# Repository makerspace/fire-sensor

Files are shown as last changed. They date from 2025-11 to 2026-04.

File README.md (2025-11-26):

# Fire sensor for Stockholm Makerspace

This ESP32-based sensor monitors the fire-safety system of the [big dust collector](https://wiki.makerspace.se/Sp%C3%A5nsug,_Felder_RL_125) in the [Stockholm Makerspace](https://makerspace.se) Wood Workshop.
If a fire is detected, a POST request is sent to a URL, which will (presumably) then notify people that something bad is happening.

It monitors:

* A temperature sensor.
* A relay for the pressure sensor on the fire-safety system's water tank.
* A distance sensor, used for measuring the amount of dust in the dust bin.
* A relay for the distance sensor.

## Installation

### Pre-requisites

```bash
# Use Linux. It might be compatible with macOS, but likely not.

# Install rust
open https://rustup.rs/

cargo install ldproxy

# Install espup to manage the esp toolchain
cargo install espup --locked

# Install the esp toolchain
espup install

# Install espflash wrapper for cargo
cargo install cargo-espflash

# Clone this repository
git clone https://github.com/makerspace/fire-sensor.git
cd fire-sensor
```

### Flashing the ESP

The ESP supports both flashing via USB, and updates over wifi.

To flash via a connected USB cable, use
```bash
make flash
```

To flash to a powered-on ESP32 module on the same network, use:
```bash
make ota
```

Note: The MAC-address of the ESP32 module is hardcoded in the Makefile.

Note: The ESP32 will connect to the *Stockholm Makerspace Wifi* on startup. You must be on this network to be able to flash it wirelessly.

If the flash failed and the ESP32 cannot start properly, it will automatically revert to the previous firmware.

## Data logging

The ESP32 can connect to an MQTT broker (see config details in `main.rs`) to continuously log all sensor values.
This can also be used to send alerts, or even alerts for if the ESP32 loses power or breaks for some reason.

It will log the following data to the given MQTT topics:

```
sync/devices/{device_id}/status: JSON string, "online" | "offline". Uses MQTT last-will-and-testament to set the status to "offline" if the device goes down.
sync/devices/{device_id}/version: JSON string, "#{git hash} {timestamp}". The git hash of the commit the firmware was last flashed with, and the timestamp of the last build.
sync/dust_collector/{device_id}/temperature: Option<f32>, the temperature in degrees Celcius as given by the attached temperature sensor.
sync/dust_collector/{device_id}/water_pressure: Option<bool>, true when there's positive pressure.
sync/dust_collector/{device_id}/dust_level: Option<u16>, sensor value from the ultrasonic distance sensor.
sync/dust_collector/{device_id}/dust_level_warning_1: Option<bool>, true when the dust level is too high.
sync/dust_collector/{device_id}/dust_level_warning_2: Option<bool>, true when the dust level is very high and the machine will be turned off.
sync/dust_collector/{device_id}/machine_running: Option<bool>, true when the machine is running.
sync/dust_collector/{device_id}/powered_on_too_long: Option<bool>, true when the gates have been opened for too long, and the machine has been turned off automatically.
sync/dust_collector/{device_id}/gates/N/open: Option<bool>, true when the gate is open
```

Where `device_id` is `fire_sensor {MAC ADDRESS OF ESP32}`.

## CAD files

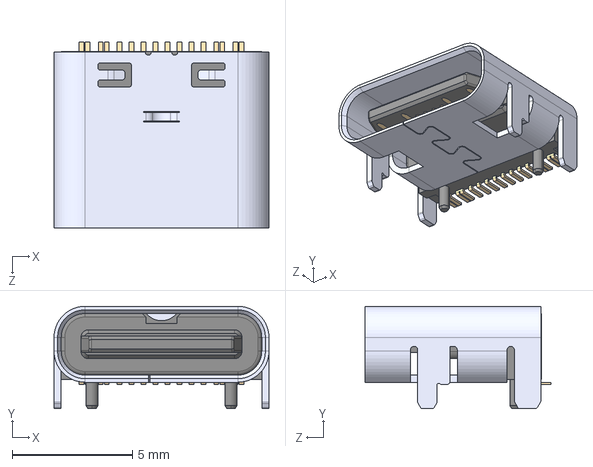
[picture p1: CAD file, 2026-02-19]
schematic2/3D_models/CSP-USC16-TR--3DModel-STEP-468060.STEP
8.94 x 4.26 x 7.75 mm

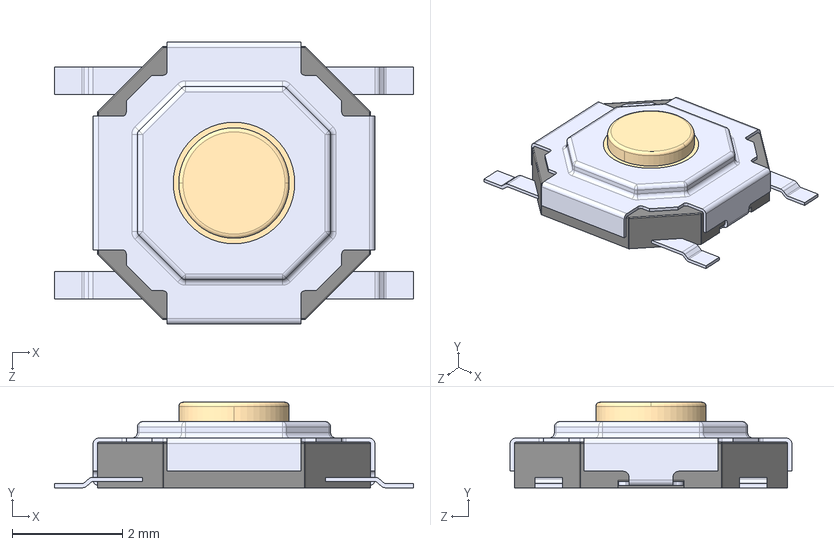
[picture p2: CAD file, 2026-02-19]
schematic2/3D_models/TS-1187A-B-A-B--3DModel-STEP-56544.STEP
6.50 x 1.55 x 5.10 mm

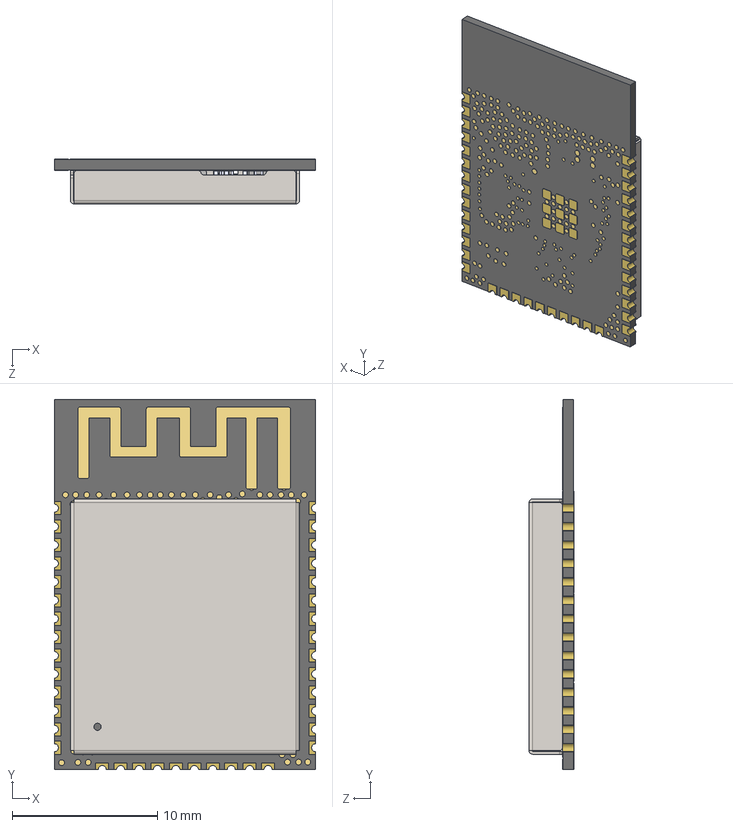
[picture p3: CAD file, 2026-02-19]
schematic2/3D_models/ESP32-WROOM-32E.STEP
18.0 x 25.5 x 3.10 mm
ESP32_5x5_20210301.STEP^ESP32_5x5_20210301.STEP_Submodel-SLP48_5X5_part_DesignRootModel_PCB_ESP32-WROOM-32E_V1(2)_PCB_ESP32-WROOM-32E_V1
trace_1^Submodel-ANT_L_TYPEA_1501846164_part_DesignRootModel_PCB_ESP32-WROOM-32E_V1(2)_PCB_ESP32-WROOM-32E_V1
DFN1006.STEP^DFN1006.STEP_Submodel-SOD882_part_DesignRootModel_PCB_ESP32-WROOM-32E_V1(2)_PCB_ESP32-WROOM-32E_V1
R0201_20210301.STEP^R0201_20210301.STEP_Submodel-R0201_part_DesignRootModel_PCB_ESP32-WROOM-32E_V1(2)_PCB_ESP32-WROOM-32E_V1 x 3
L0201_20210301.STEP^L0201_20210301.STEP_Submodel-L0201_part_DesignRootModel_PCB_ESP32-WROOM-32E_V1(2)_PCB_ESP32-WROOM-32E_V1 x 2
C0201_20210301.STEP^C0201_20210301.STEP_Submodel-C0201_part_DesignRootModel_PCB_ESP32-WROOM-32E_V1(2)_PCB_ESP32-WROOM-32E_V1 x 17
SOIC8_208_20210301.STEP^SOIC8_208_20210301.STEP_Submodel-SOIC08-WN_part_DesignRootModel_PCB_ESP32-WROOM-32E_V1(2)_PCB_ESP32-WROOM-32E_V1
XTAL3225_20210301.STEP^XTAL3225_20210301.STEP_Submodel-3225_part_DesignRootModel_PCB_ESP32-WROOM-32E_V1(2)_PCB_ESP32-WROOM-32E_V1
C0402_20210301.STEP^C0402_20210301.STEP_Submodel-0402A_part_DesignRootModel_PCB_ESP32-WROOM-32E_V1(2)_PCB_ESP32-WROOM-32E_V1 x 2
uid__1-311^DesignRootModel_PCB_ESP32-WROOM-32E_V1(2)_PCB_ESP32-WROOM-32E_V1
uid__1-312^DesignRootModel_PCB_ESP32-WROOM-32E_V1(2)_PCB_ESP32-WROOM-32E_V1
uid__1-313^DesignRootModel_PCB_ESP32-WROOM-32E_V1(2)_PCB_ESP32-WROOM-32E_V1
uid__1-314^DesignRootModel_PCB_ESP32-WROOM-32E_V1(2)_PCB_ESP32-WROOM-32E_V1
uid__1-315^DesignRootModel_PCB_ESP32-WROOM-32E_V1(2)_PCB_ESP32-WROOM-32E_V1
uid__1-316^DesignRootModel_PCB_ESP32-WROOM-32E_V1(2)_PCB_ESP32-WROOM-32E_V1
uid__1-317^DesignRootModel_PCB_ESP32-WROOM-32E_V1(2)_PCB_ESP32-WROOM-32E_V1
uid__1-318^DesignRootModel_PCB_ESP32-WROOM-32E_V1(2)_PCB_ESP32-WROOM-32E_V1
uid__1-319^DesignRootModel_PCB_ESP32-WROOM-32E_V1(2)_PCB_ESP32-WROOM-32E_V1
uid__1-320^DesignRootModel_PCB_ESP32-WROOM-32E_V1(2)_PCB_ESP32-WROOM-32E_V1
uid__1-321^DesignRootModel_PCB_ESP32-WROOM-32E_V1(2)_PCB_ESP32-WROOM-32E_V1
uid__1-322^DesignRootModel_PCB_ESP32-WROOM-32E_V1(2)_PCB_ESP32-WROOM-32E_V1
uid__1-323^DesignRootModel_PCB_ESP32-WROOM-32E_V1(2)_PCB_ESP32-WROOM-32E_V1
uid__1-324^DesignRootModel_PCB_ESP32-WROOM-32E_V1(2)_PCB_ESP32-WROOM-32E_V1
uid__1-325^DesignRootModel_PCB_ESP32-WROOM-32E_V1(2)_PCB_ESP32-WROOM-32E_V1
uid__1-326^DesignRootModel_PCB_ESP32-WROOM-32E_V1(2)_PCB_ESP32-WROOM-32E_V1
uid__1-327^DesignRootModel_PCB_ESP32-WROOM-32E_V1(2)_PCB_ESP32-WROOM-32E_V1
uid__1-328^DesignRootModel_PCB_ESP32-WROOM-32E_V1(2)_PCB_ESP32-WROOM-32E_V1
uid__1-329^DesignRootModel_PCB_ESP32-WROOM-32E_V1(2)_PCB_ESP32-WROOM-32E_V1
uid__1-330^DesignRootModel_PCB_ESP32-WROOM-32E_V1(2)_PCB_ESP32-WROOM-32E_V1
uid__1-331^DesignRootModel_PCB_ESP32-WROOM-32E_V1(2)_PCB_ESP32-WROOM-32E_V1
uid__1-332^DesignRootModel_PCB_ESP32-WROOM-32E_V1(2)_PCB_ESP32-WROOM-32E_V1
uid__1-333^DesignRootModel_PCB_ESP32-WROOM-32E_V1(2)_PCB_ESP32-WROOM-32E_V1
uid__1-334^DesignRootModel_PCB_ESP32-WROOM-32E_V1(2)_PCB_ESP32-WROOM-32E_V1
uid__1-335^DesignRootModel_PCB_ESP32-WROOM-32E_V1(2)_PCB_ESP32-WROOM-32E_V1
uid__1-336^DesignRootModel_PCB_ESP32-WROOM-32E_V1(2)_PCB_ESP32-WROOM-32E_V1
uid__1-337^DesignRootModel_PCB_ESP32-WROOM-32E_V1(2)_PCB_ESP32-WROOM-32E_V1
uid__1-338^DesignRootModel_PCB_ESP32-WROOM-32E_V1(2)_PCB_ESP32-WROOM-32E_V1
uid__1-339^DesignRootModel_PCB_ESP32-WROOM-32E_V1(2)_PCB_ESP32-WROOM-32E_V1
uid__1-340^DesignRootModel_PCB_ESP32-WROOM-32E_V1(2)_PCB_ESP32-WROOM-32E_V1
uid__1-341^DesignRootModel_PCB_ESP32-WROOM-32E_V1(2)_PCB_ESP32-WROOM-32E_V1
uid__1-342^DesignRootModel_PCB_ESP32-WROOM-32E_V1(2)_PCB_ESP32-WROOM-32E_V1
uid__1-343^DesignRootModel_PCB_ESP32-WROOM-32E_V1(2)_PCB_ESP32-WROOM-32E_V1
uid__1-344^DesignRootModel_PCB_ESP32-WROOM-32E_V1(2)_PCB_ESP32-WROOM-32E_V1
uid__1-345^DesignRootModel_PCB_ESP32-WROOM-32E_V1(2)_PCB_ESP32-WROOM-32E_V1
uid__1-346^DesignRootModel_PCB_ESP32-WROOM-32E_V1(2)_PCB_ESP32-WROOM-32E_V1
uid__1-347^DesignRootModel_PCB_ESP32-WROOM-32E_V1(2)_PCB_ESP32-WROOM-32E_V1
uid__1-348^DesignRootModel_PCB_ESP32-WROOM-32E_V1(2)_PCB_ESP32-WROOM-32E_V1
uid__1-349^DesignRootModel_PCB_ESP32-WROOM-32E_V1(2)_PCB_ESP32-WROOM-32E_V1
uid__1-350^DesignRootModel_PCB_ESP32-WROOM-32E_V1(2)_PCB_ESP32-WROOM-32E_V1
uid__1-351^DesignRootModel_PCB_ESP32-WROOM-32E_V1(2)_PCB_ESP32-WROOM-32E_V1
uid__1-352^DesignRootModel_PCB_ESP32-WROOM-32E_V1(2)_PCB_ESP32-WROOM-32E_V1
uid__1-353^DesignRootModel_PCB_ESP32-WROOM-32E_V1(2)_PCB_ESP32-WROOM-32E_V1
uid__1-354^DesignRootModel_PCB_ESP32-WROOM-32E_V1(2)_PCB_ESP32-WROOM-32E_V1
uid__1-355^DesignRootModel_PCB_ESP32-WROOM-32E_V1(2)_PCB_ESP32-WROOM-32E_V1
uid__1-356^DesignRootModel_PCB_ESP32-WROOM-32E_V1(2)_PCB_ESP32-WROOM-32E_V1
uid__1-357^DesignRootModel_PCB_ESP32-WROOM-32E_V1(2)_PCB_ESP32-WROOM-32E_V1
uid__1-359^DesignRootModel_PCB_ESP32-WROOM-32E_V1(2)_PCB_ESP32-WROOM-32E_V1
uid__1-360^DesignRootModel_PCB_ESP32-WROOM-32E_V1(2)_PCB_ESP32-WROOM-32E_V1
uid__1-361^DesignRootModel_PCB_ESP32-WROOM-32E_V1(2)_PCB_ESP32-WROOM-32E_V1
uid__1-362^DesignRootModel_PCB_ESP32-WROOM-32E_V1(2)_PCB_ESP32-WROOM-32E_V1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

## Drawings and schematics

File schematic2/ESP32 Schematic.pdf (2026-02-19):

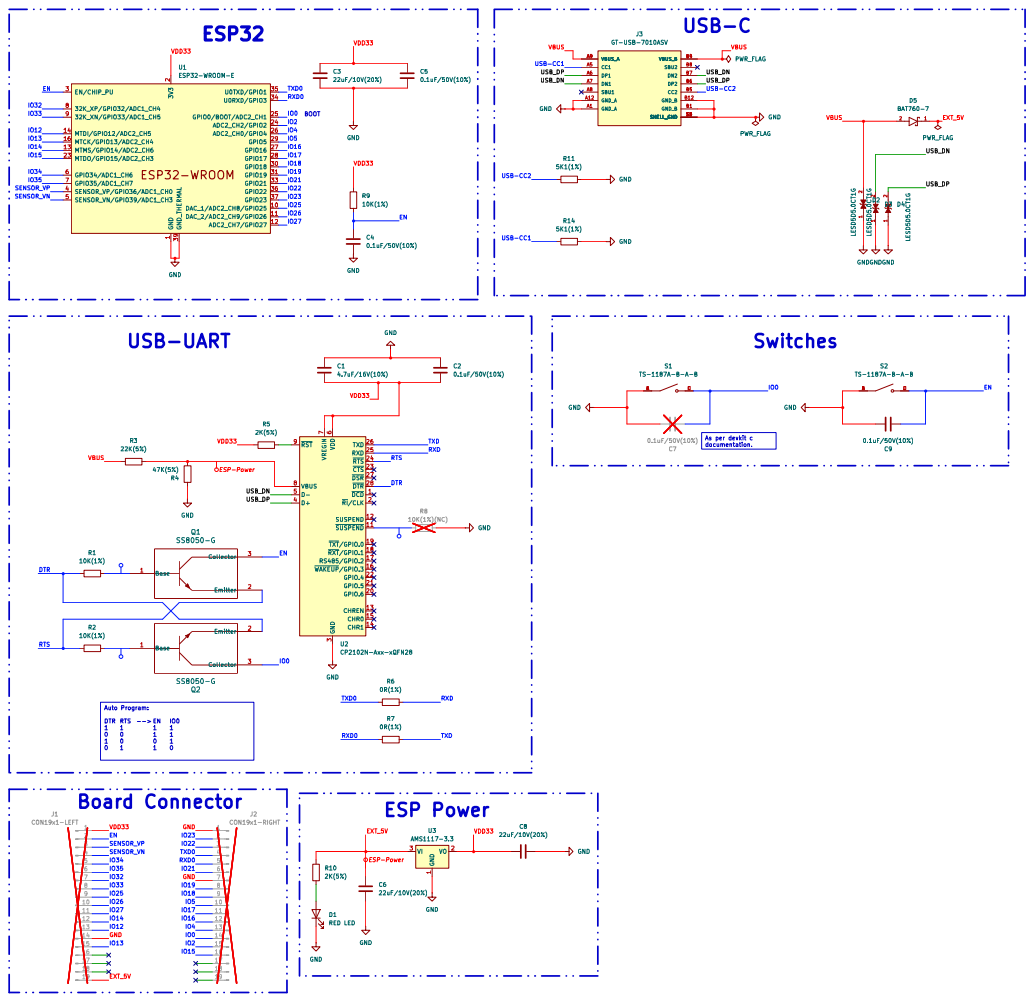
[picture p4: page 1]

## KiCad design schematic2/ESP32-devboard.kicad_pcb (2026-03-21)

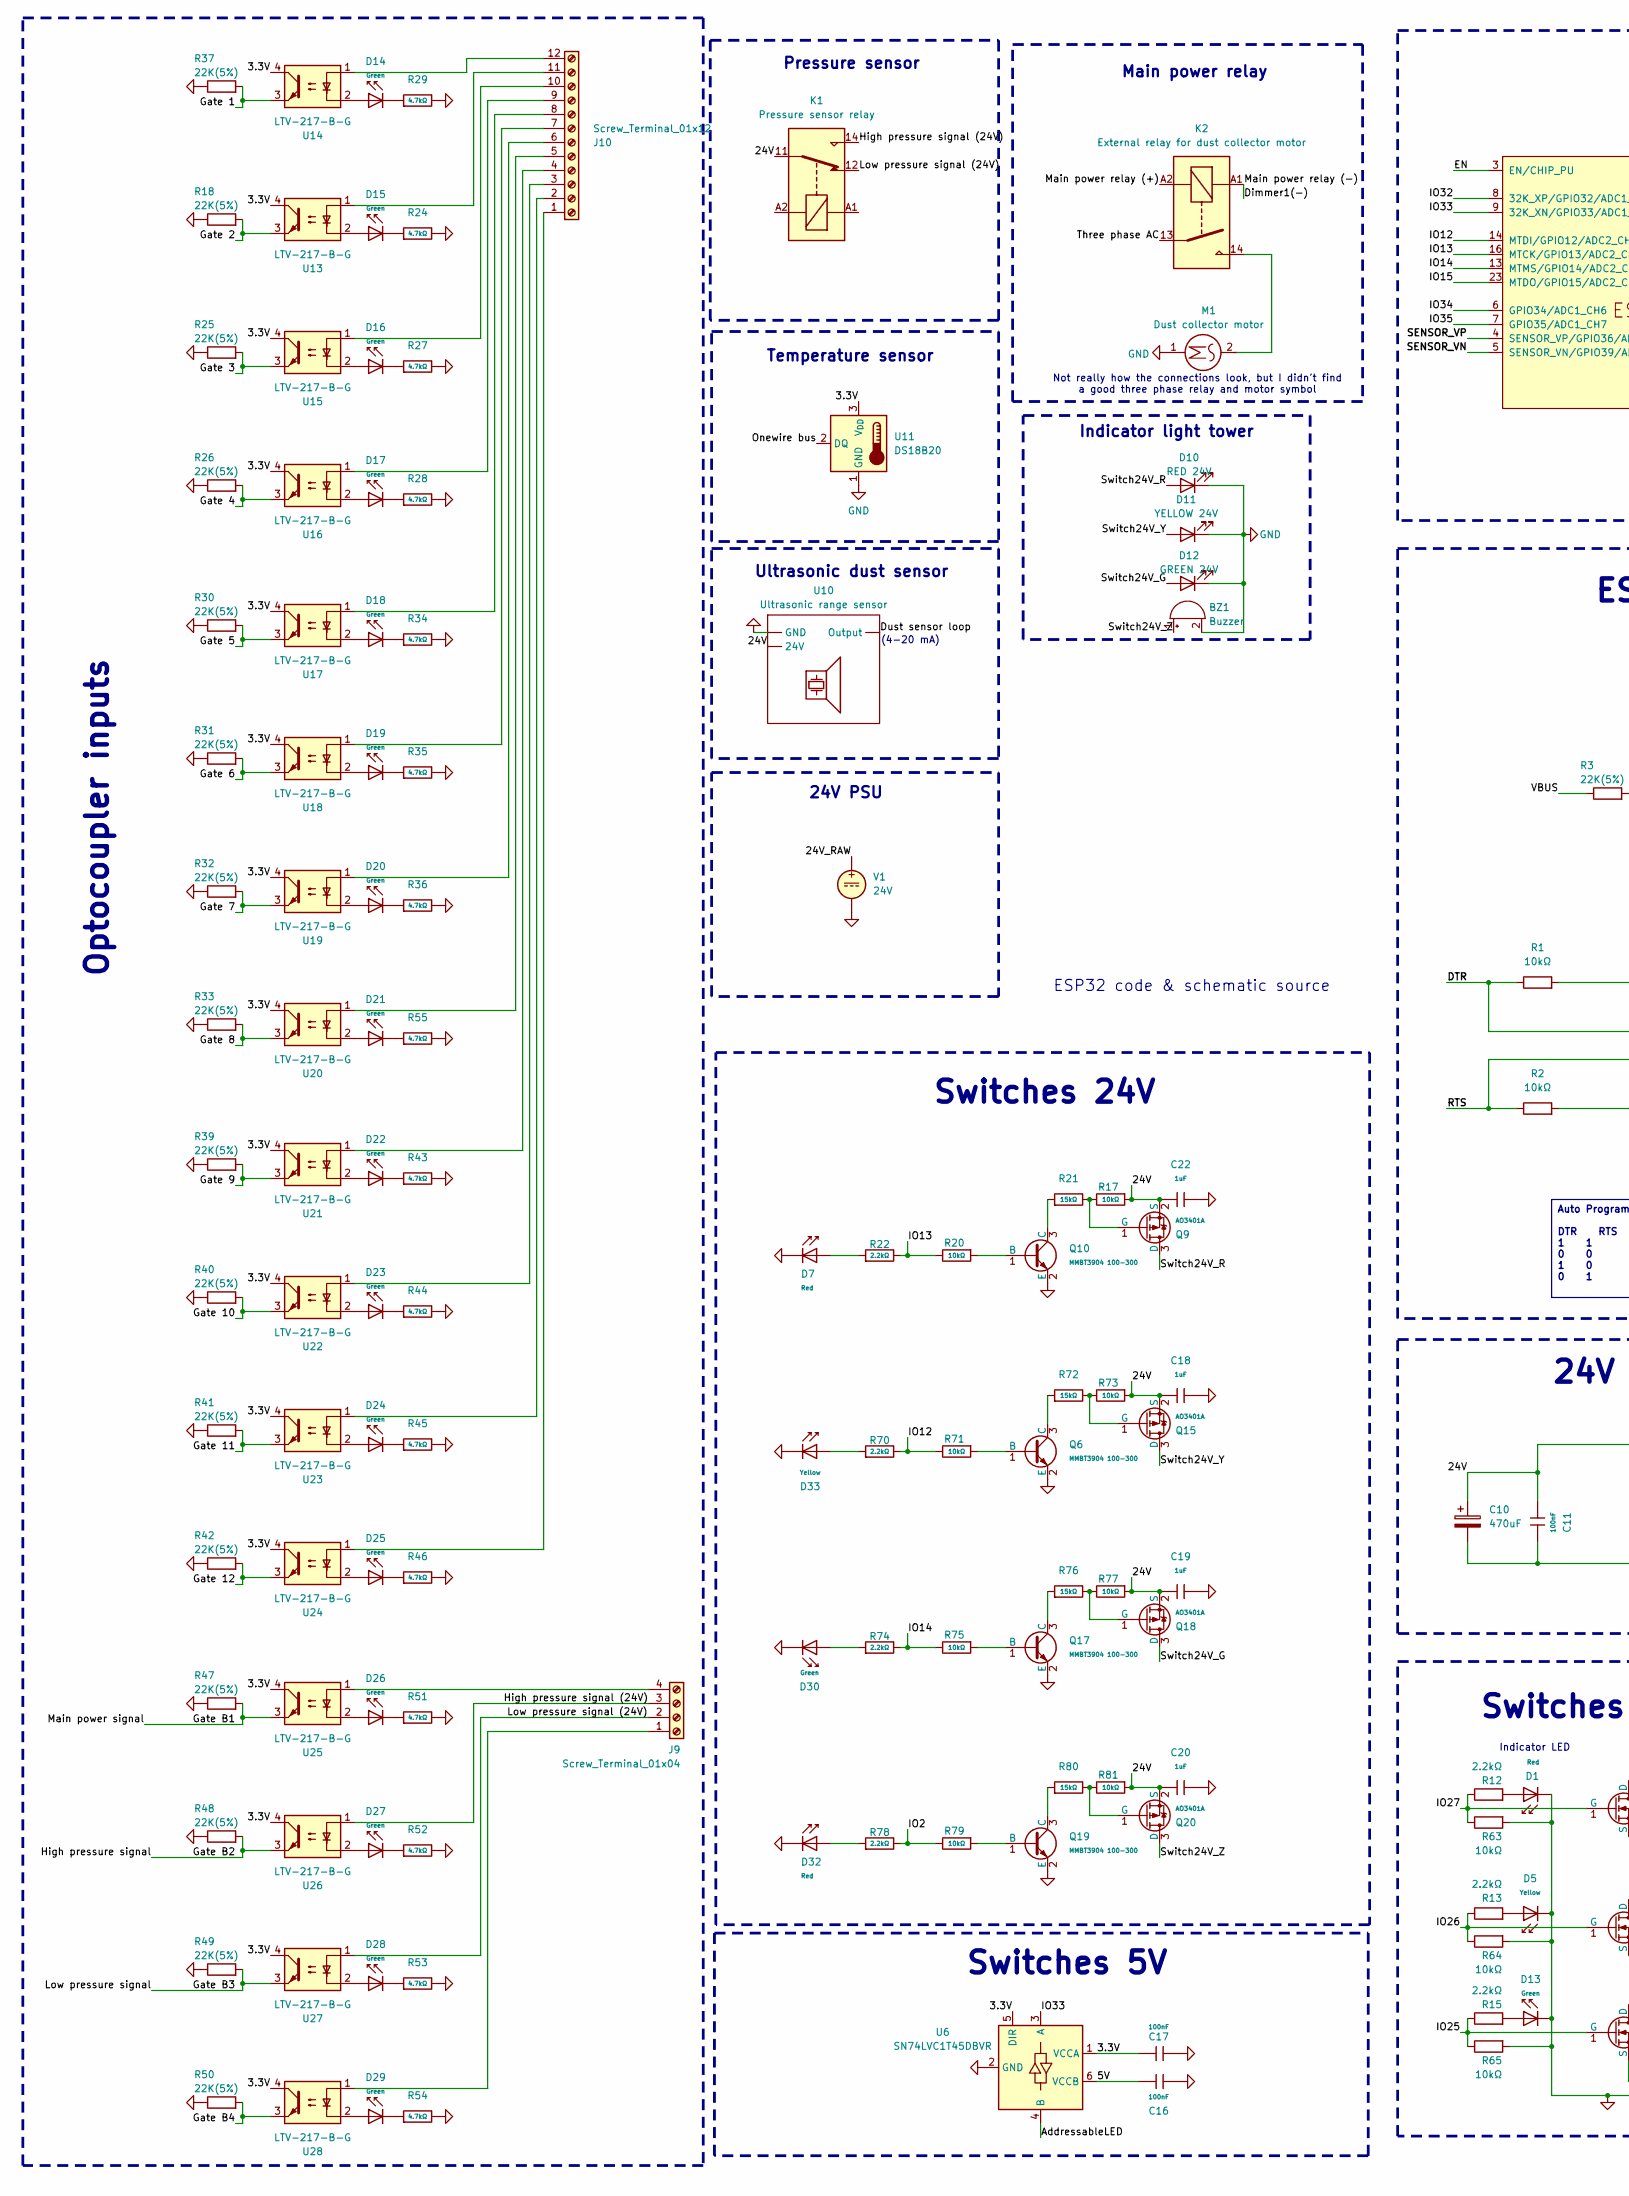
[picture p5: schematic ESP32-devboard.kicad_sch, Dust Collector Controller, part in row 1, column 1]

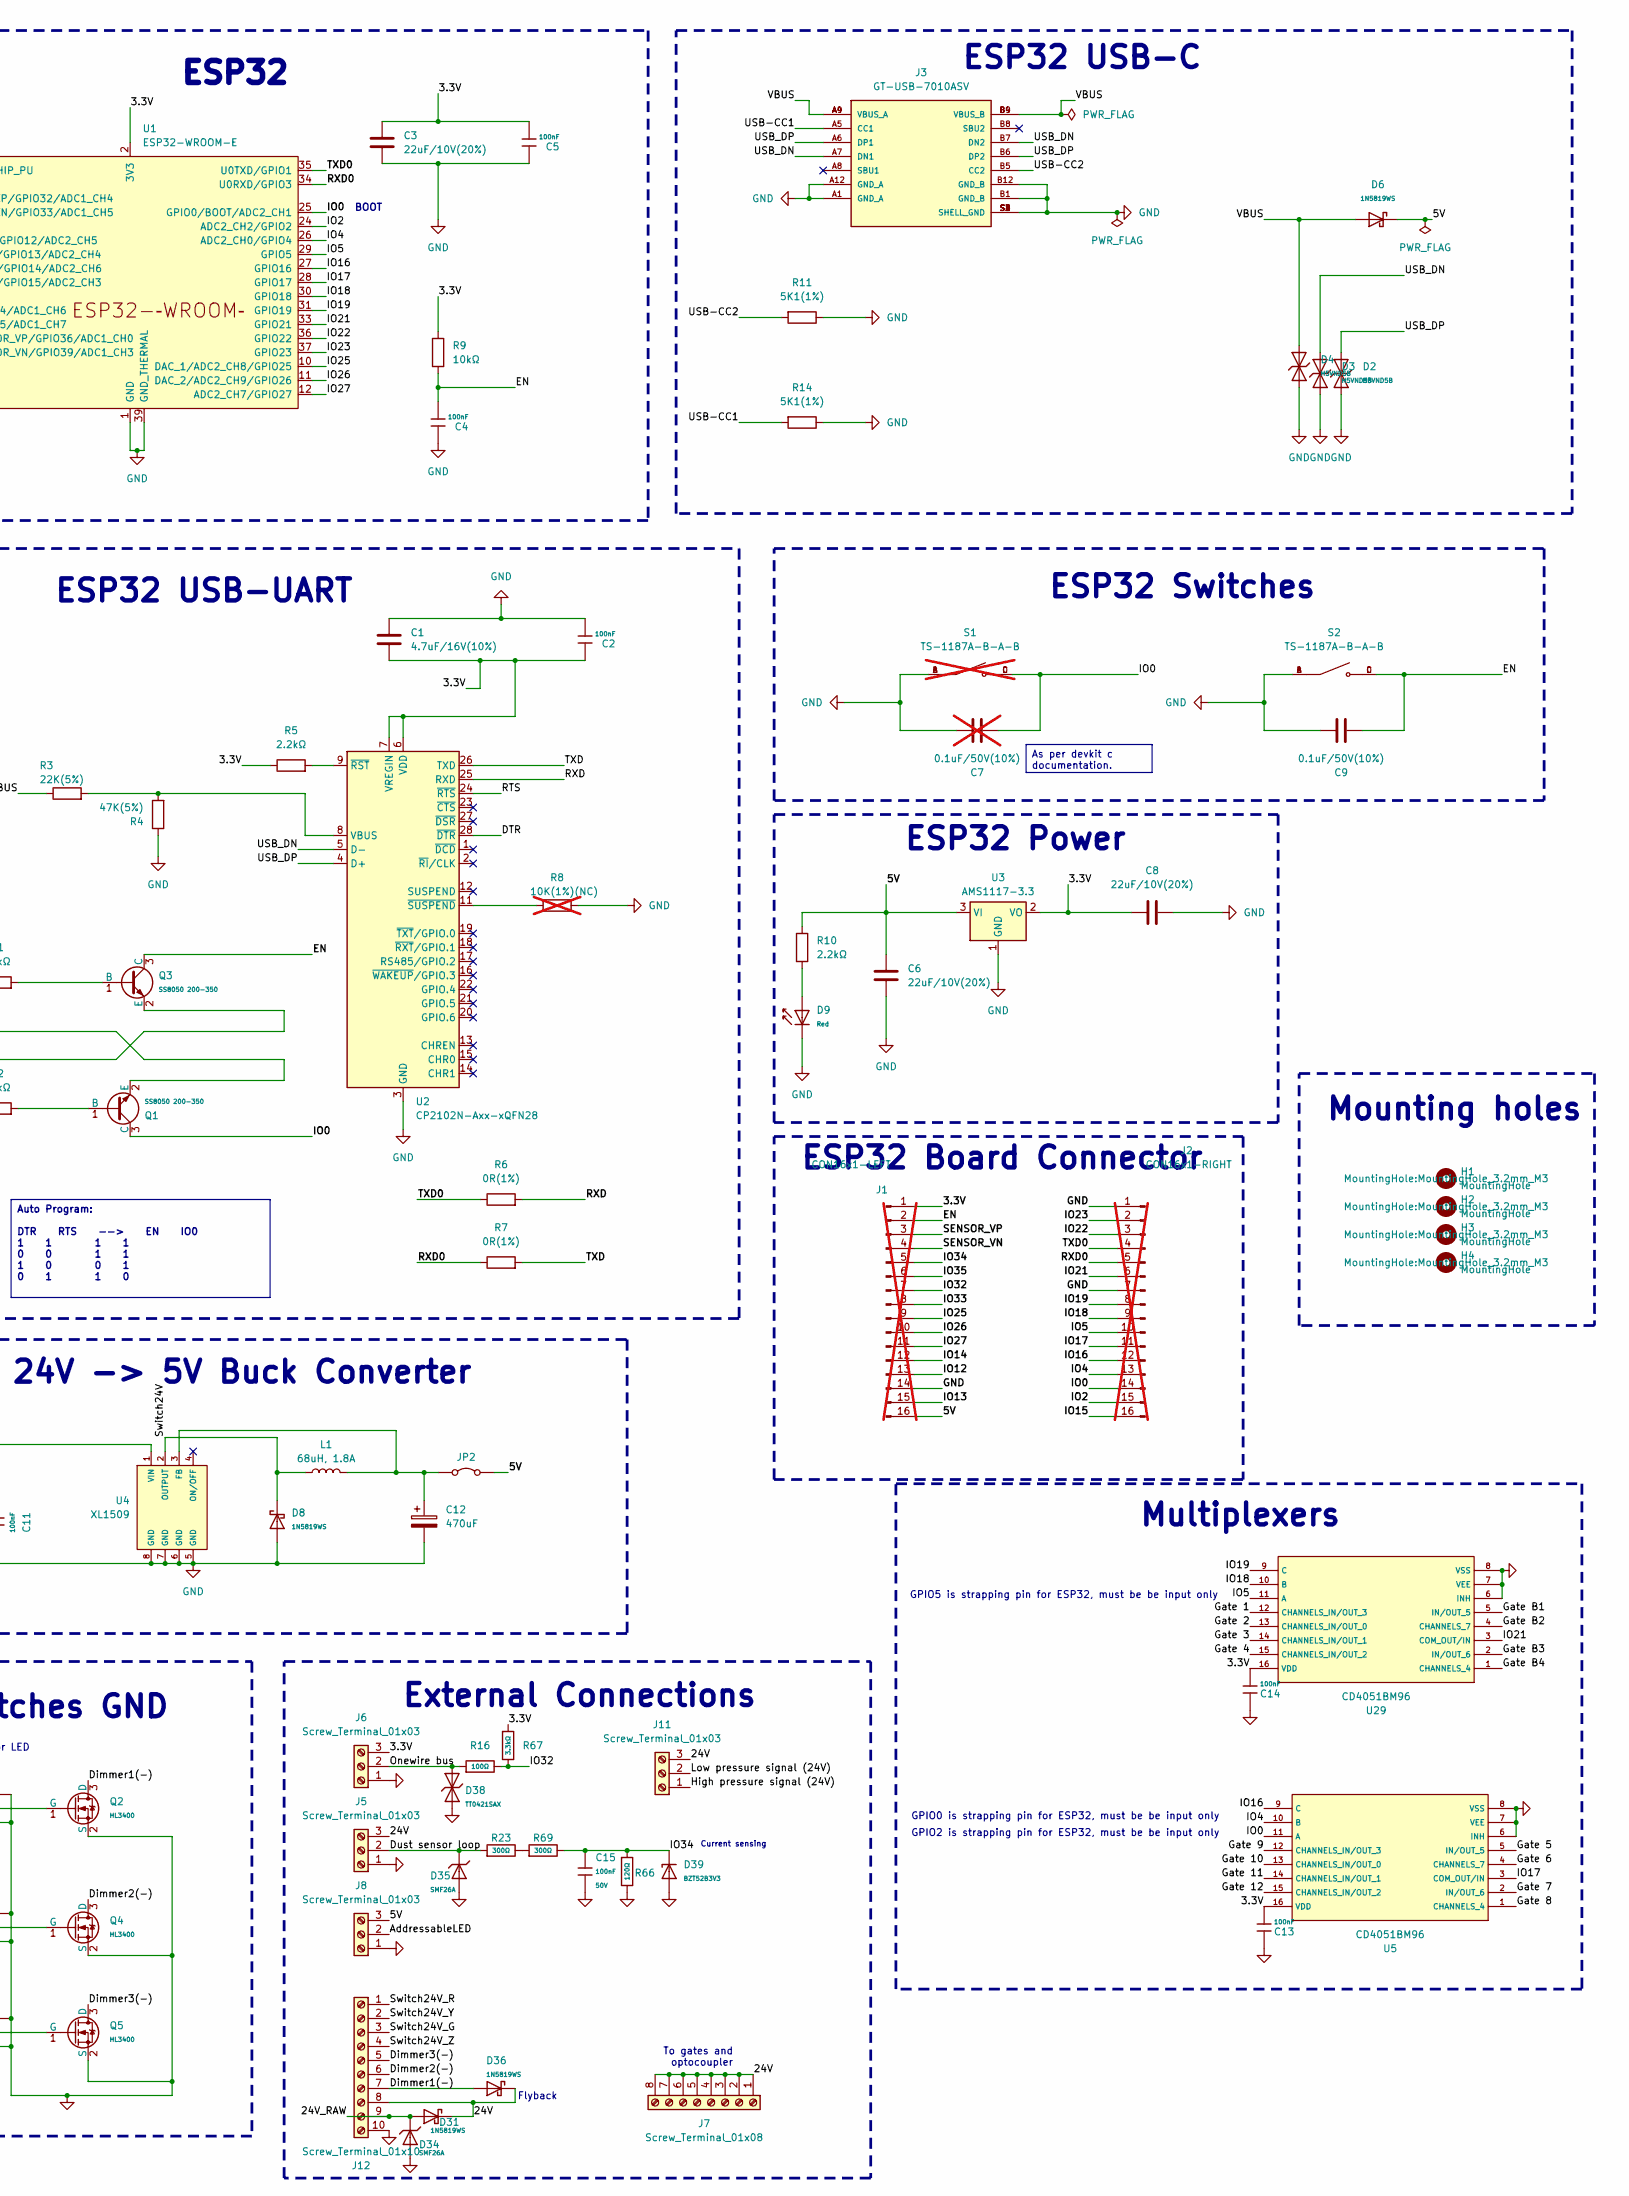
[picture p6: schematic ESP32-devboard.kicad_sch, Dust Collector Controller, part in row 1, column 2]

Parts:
BZ1: Buzzer
C1: 4.7uF/16V(10%); C_0603_1608Metric; LCSC C19666
C2, C4, C5, C11, C13, C14, C15, C16, C17: 100nF; C_0603; Voltage Rated 50V; Tolerance ±10%; Part CC0603KRX7R9BB104; LCSC C14663
C3, C6, C8: 22uF/10V(20%); C_0805_2012Metric; LCSC C45783
C7: 0.1uF/50V(10%); C_0402_1005Metric; LCSC C307331; not fitted
C9: 0.1uF/50V(10%); C_0402_1005Metric; LCSC C307331
C10, C12: 470uF; CP_Radial_D10.0mm_P5.00mm
C18, C19, C20, C22: 1uF; C_0603; Voltage Rated 50V; Tolerance ±10%; Part CL10A105KB8NNNC; LCSC C15849
D1, D7, D9, D32: Red; D_0603; Part KT-0603R; LCSC C2286
D2, D3, D4: H5VND5B; D_SOD-523; Part H5VND5B; LCSC C20615818
D5, D33: Yellow; D_0805; Part KT-0805Y; LCSC C2296
D6, D8, D31, D36: 1N5819WS; D_SOD-323; Forward Voltage (Vf@If) 600mV@1A; Reverse Voltage (Vr) 40V; Part 1N5819WS; LCSC C191023
D10: RED 24V
D11: YELLOW 24V
D12: GREEN 24V
D13, D14, D15, D16, D17, D18, D19, D20, D21, D22, D23, D24, D25, D26, D27, D28, D29, D30: Green; D_0805; Part KT-0805G; LCSC C2297
D34, D35: SMF26A; D_SOD-123FL; Clamping Voltage 42.1V; Voltage - Breakdown 31.9V; Part SMF26A; LCSC C41376090
D38: TT0421SAX; D_DFN0603-2L; Clamping Voltage 4.5V; Voltage Breakdown 9V; Part TT0421SAX; LCSC C5364033
D39: BZT52B3V3; D_SOD-123; Part BZT52B3V3; LCSC C19077392
H1, H2, H3, H4: MountingHole; MountingHole_3.2mm_M3
J1: CON16x1-LEFT; PinSocket_1x16_P2.54mm_Vertical; not fitted
J2: CON16x1-RIGHT; PinSocket_1x16_P2.54mm_Vertical; not fitted
J3: GT-USB-7010ASV; GT-USB-7010; LCSC C2988369
J5, J6, J8, J11: Screw_Terminal_01x03; PinHeader_1x03_P2.54mm_Horizontal
J7: Screw_Terminal_01x08; TerminalBlock_Phoenix_MKDS-1,5-8_1x08_P5.00mm_Horizontal
J9: Screw_Terminal_01x04; TerminalBlock_Phoenix_MKDS-1,5-4_1x04_P5.00mm_Horizontal
J10: Screw_Terminal_01x12; TerminalBlock_Phoenix_MKDS-1,5-12_1x12_P5.00mm_Horizontal
J12: Screw_Terminal_01x10; TerminalBlock_Phoenix_MKDS-1,5-10_1x10_P5.00mm_Horizontal
JP2: Jumper_2_Bridged; PinHeader_1x02_P2.54mm_Vertical
K1: Pressure sensor relay; Relay_SPDT_Fujitsu_FTR-LYCA005x_FormC_Vertical
K2: External relay for dust collector motor; Relay_SPST-NO_Fujitsu_FTR-LYAA005x_FormA_Vertical
L1: 68uH, 1.8A; Inductor C5189964; LCSC C5189964
M1: Dust collector motor
Q1, Q3: SS8050 200-350; Q_SOT-23; Part SS8050(RANGE:200-350); LCSC C2150
Q2, Q4, Q5: HL3400; Q_SOT-23; Part HL3400; LCSC C22469448
Q6, Q10, Q17, Q19: MMBT3904 100-300; Q_SOT-23; Part MMBT3904(RANGE:100-300); LCSC C20526
Q9, Q15, Q18, Q20: AO3401A; Q_SOT-23; Part AO3401A; LCSC C15127
R1, R2, R9, R63, R64, R65: 10kΩ; R_0603; LCSC C25804
R3, R18, R25, R26, R30, R31, R32, R33, R37, R39, R40, R41, R42, R47, R48, R49, R50: 22K(5%); R_0603; LCSC C31850
R4: 47K(5%); R_0603; LCSC C25819
R5, R10, R12, R13, R15: 2.2kΩ; R_0603; LCSC C4190
R6, R7: 0R(1%); C_0402_1005Metric; LCSC C17168
R8: 10K(1%)(NC); C_0603_1608Metric; LCSC C25804; not fitted
R11, R14: 5K1(1%); R_0402_1005Metric; LCSC C25905
R16: 100Ω; R_0402; Overload Voltage (Max) 50V; Tolerance ±1%; Part 0402WGF1000TCE; LCSC C25076
R17, R20, R71, R73, R75, R77, R79, R81: 10kΩ; R_0603; Overload Voltage (Max) 75V; Tolerance ±1%; Part 0603WAF1002T5E; LCSC C25804
R21, R72, R76, R80: 15kΩ; R_0603; Overload Voltage (Max) 75V; Tolerance ±1%; Part 0603WAF1502T5E; LCSC C22809
R22, R70, R74, R78: 2.2kΩ; R_0603; Overload Voltage (Max) 75V; Tolerance ±1%; Part 0603WAF2201T5E; LCSC C4190
R23, R69: 300Ω; R_1206; Overload Voltage (Max) 200V; Tolerance ±1%; Part 1206W4F3000T5E; LCSC C17887
R24, R27, R28, R29, R34, R35, R36, R43, R44, R45, R46, R51, R52, R53, R54, R55: 4.7kΩ; R_0603; Overload Voltage (Max) 75V; Tolerance ±1%; Part 0603WAF4701T5E; LCSC C23162
R66: 120Ω; R_0603; Overload Voltage (Max) 75V; Tolerance ±1%; Part 0603WAF1200T5E; LCSC C22787
R67: 3.3kΩ; R_0402; Overload Voltage (Max) 50V; Tolerance ±1%; Part 0402WGF3301TCE; LCSC C25890
S1: TS-1187A-B-A-B; SW_TS-1187A-B-A-B; PARTREV A0; LCSC C318884; not fitted
S2: TS-1187A-B-A-B; SW_TS-1187A-B-A-B; PARTREV A0; LCSC C318884
U1: ESP32-WROOM-E; ESP32-WROOM-32E; LCSC C701342
U2: CP2102N-Axx-xQFN28; QFN-28-1EP_5x5mm_P0.5mm_EP3.35x3.35mm; LCSC C964632
U3: AMS1117-3.3; SOT-223-3_TabPin2; LCSC C6186
U4: XL1509; SOIC-8_L5.0-W4.0-P1.27-LS6.0-BL; Output Voltage 5V; Input Voltage 4.5V~40V; Part XL1509-5.0E1; LCSC C61063
U5, U29: CD4051BM96; SOIC-16_L9.9-W3.9-P1.27-LS6.0-BL; Supply Voltage 3V~20V; Part CD4051BM96; LCSC C21379
U6: SN74LVC1T45DBVR; SOT-23-6; LCSC C7843
U10: Ultrasonic range sensor
U11: DS18B20; TO-92_Inline
U13, U14, U15, U16, U17, U18, U19, U20, U21, U22, U23, U24, U25, U26, U27, U28: LTV-217-B-G; SOP-4_4.4x2.6mm_P1.27mm; Part LTV-217-B-G; LCSC C115450
V1: 24V

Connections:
/3.3V: C1.2, C2.2, C3.1, C5.1, C8.1, C13.1, C14.1, C17.1, J1.1, J6.3, R5.1, R9.1, R67.1, U1.2 (3V3), U2.6 (VDD), U2.7 (VREGIN), U3.2 (VO), U5.16 (VDD), U6.1 (VCCA), U6.5 (DIR), U11.3 (V_{DD}), U13.4, U14.4, U15.4, U16.4, U17.4, U18.4, U19.4, U20.4, U21.4, U22.4, U23.4, U24.4, U25.4, U26.4, U27.4, U28.4, U29.16 (VDD)
/5V: C6.1, C16.1, D6.1, J1.16, J8.3, JP2.2 (B), R10.1, U3.3 (VI), U6.6 (VCCB)
/24V: C10.1, C11.2, C18.1, C19.1, C20.1, C22.1, D31.1, D36.1, J5.3, J7.1, J7.2, J7.3, J7.4, J7.5, J7.6, J7.7, J7.8, J11.3, J12.8, K1.11, Q9.2 (S), Q15.2 (S), Q18.2 (S), Q20.2 (S), R17.1, R73.1, R77.1, R81.1, U4.1 (VIN), U10.
/24V_RAW: D31.2, D34.1, J12.9, V1.1
/AddressableLED: J8.2, U6.4 (B)
/DTR: Q1.2 (E), R1.1, U2.28 (~DTR)
/Dimmer1(-): D36.2, J12.7, K2.A1, Q2.3 (D)
/Dimmer2(-): J12.6, Q4.3 (D)
/Dimmer3(-): J12.5, Q5.3 (D)
/Dust sensor loop: D35.1, J5.2, R23.1, U10.
/EN: C4.1, C9.1, J1.2, Q3.3 (C), R9.2, S2.C, S2.D, U1.3 (EN/CHIP_PU)
/Gate 1: R37.2, U14.3, U29.12 (CHANNELS_IN/OUT_3)
/Gate 2: R18.2, U13.3, U29.13 (CHANNELS_IN/OUT_0)
/Gate 3: R25.2, U15.3, U29.14 (CHANNELS_IN/OUT_1)
/Gate 4: R26.2, U16.3, U29.15 (CHANNELS_IN/OUT_2)
/Gate 5: R30.2, U5.5 (IN/OUT_5), U17.3
/Gate 6: R31.2, U5.4 (CHANNELS_7), U18.3
/Gate 7: R32.2, U5.2 (IN/OUT_6), U19.3
/Gate 8: R33.2, U5.1 (CHANNELS_4), U20.3
/Gate 9: R39.2, U5.12 (CHANNELS_IN/OUT_3), U21.3
/Gate 10: R40.2, U5.13 (CHANNELS_IN/OUT_0), U22.3
/Gate 11: R41.2, U5.14 (CHANNELS_IN/OUT_1), U23.3
/Gate 12: R42.2, U5.15 (CHANNELS_IN/OUT_2), U24.3
/Gate B1: R47.2, U25.3, U29.5 (IN/OUT_5)
/Gate B2: R48.2, U26.3, U29.4 (CHANNELS_7)
/Gate B3: R49.2, U27.3, U29.2 (IN/OUT_6)
/Gate B4: R50.2, U28.3, U29.1 (CHANNELS_4)
/High pressure signal (24V): J9.3, J11.1, K1.14, U26.1
/IO0: C7.1, J2.14, Q1.3 (C), S1.C, S1.D, U1.25 (GPIO0/BOOT/ADC2_CH1), U5.11 (A)
/IO2: J2.15, R78.2, R79.2, U1.24 (ADC2_CH2/GPIO2)
/IO4: J2.13, U1.26 (ADC2_CH0/GPIO4), U5.10 (B)
/IO5: J2.10, U1.29 (GPIO5), U29.11 (A)
/IO12: J1.13, R70.2, R71.2, U1.14 (MTDI/GPIO12/ADC2_CH5)
/IO13: J1.15, R20.2, R22.2, U1.16 (MTCK/GPIO13/ADC2_CH4)
/IO14: J1.12, R74.2, R75.2, U1.13 (MTMS/GPIO14/ADC2_CH6)
/IO15: J2.16, U1.23 (MTDO/GPIO15/ADC2_CH3)
/IO16: J2.12, U1.27 (GPIO16), U5.9 (C)
/IO17: J2.11, U1.28 (GPIO17), U5.3 (COM_OUT/IN)
/IO18: J2.9, U1.30 (GPIO18), U29.10 (B)
/IO19: J2.8, U1.31 (GPIO19), U29.9 (C)
/IO21: J2.6, U1.33 (GPIO21), U29.3 (COM_OUT/IN)
/IO22: J2.3, U1.36 (GPIO22)
/IO23: J2.2, U1.37 (GPIO23)
/IO25: J1.9, Q5.1 (G), R15.1, R65.1, U1.10 (DAC_1/ADC2_CH8/GPIO25)
/IO26: J1.10, Q4.1 (G), R13.1, R64.1, U1.11 (DAC_2/ADC2_CH9/GPIO26)
/IO27: J1.11, Q2.1 (G), R12.1, R63.1, U1.12 (ADC2_CH7/GPIO27)
/IO32: J1.7, R16.2, R67.2, U1.8 (32K_XP/GPIO32/ADC1_CH4)
/IO33: J1.8, U1.9 (32K_XN/GPIO33/ADC1_CH5), U6.3 (A)
/IO34: C15.1, D39.1, J1.5, R66.1, R69.2, U1.6 (GPIO34/ADC1_CH6)
/IO35: J1.6, U1.7 (GPIO35/ADC1_CH7)
/Low pressure signal (24V): J9.2, J11.2, K1.12, U27.1
/Onewire bus: D38.2, J6.2, R16.1, U11.2 (DQ)
/RTS: Q3.2 (E), R2.1, U2.24 (~RTS)
/RXD: R6.2, U2.25 (RXD)
/RXD0: J2.5, R7.1, U1.34 (U0RXD/GPIO3)
/SENSOR_VN: J1.4, U1.5 (SENSOR_VN/GPIO39/ADC1_CH3)
/SENSOR_VP: J1.3, U1.4 (SENSOR_VP/GPIO36/ADC1_CH0)
/Switch24V: D8.1, L1.1, U4.2 (OUTPUT)
/Switch24V_G: D12.2 (A), J12.3, Q18.3 (D)
/Switch24V_R: D10.2 (A), J12.1, Q9.3 (D)
/Switch24V_Y: D11.2 (A), J12.2, Q15.3 (D)
/Switch24V_Z: BZ1.1 (+), J12.4, Q20.3 (D)
/TXD: R7.2, U2.26 (TXD)
/TXD0: J2.4, R6.1, U1.35 (U0TXD/GPIO1)
/USB-CC1: J3.A5 (CC1), R14.2
/USB-CC2: J3.B5 (CC2), R11.2
/USB_DN: D3.2, J3.A7 (DN1), J3.B7 (DN2), U2.5 (D-)
/USB_DP: D2.2, J3.A6 (DP1), J3.B6 (DP2), U2.4 (D+)
/VBUS: D4.2, D6.2, J3.A4 (VBUS_A), J3.A9 (VBUS_A), J3.B4 (VBUS_B), J3.B9 (VBUS_B), R3.1
GND: BZ1.2 (-), C1.1, C2.1, C3.2, C4.2, C5.2, C6.2, C7.2, C8.2, C9.2, C10.2, C11.1, C12.2, C13.2, C14.2, C15.2, C16.2, C17.2, C18.2, C19.2, C20.2, C22.2, D1.1, D2.1, D3.1, D4.1, D5.1, D7.1, D8.2, D9.1, D10.1 (K), D11.1 (K), D12.1 (K), D13.1, D30.1, D32.1, D33.1, D34.2, D35.2, D38.1, D39.2, J1.14, J2.1, J2.7, J3.A1 (GND_A), J3.A12 (GND_A), J3.B1 (GND_B), J3.B12 (GND_B), J3.S1 (SHELL_GND), J3.S2 (SHELL_GND), J3.S3 (SHELL_GND), J3.S4 (SHELL_GND), J5.1, J6.1, J8.1, J12.10, M1.1, Q2.2 (S), Q4.2 (S), Q5.2 (S), Q6.2 (E), Q10.2 (E), Q17.2 (E), Q19.2 (E), R4.1, R8.2, R11.1, R14.1, R18.1, R24.2, R25.1, R26.1, R27.2, R28.2, R29.2, R30.1, R31.1, R32.1, R33.1, R34.2, R35.2, R36.2, R37.1, R39.1, R40.1, R41.1, R42.1, R43.2, R44.2, R45.2, R46.2, R47.1, R48.1, R49.1, R50.1, R51.2, R52.2, R53.2, R54.2, R55.2, R63.2, R64.2, R65.2, R66.2, S1.A, S1.B, S2.A, S2.B, U1.1 (GND), U1.15 (GND), U1.38 (GND), U1.39 (GND_THERMAL), U2.3 (GND), U2.29 (GND), U3.1 (GND), U4.5 (GND), U4.6 (GND), U4.7 (GND), U4.8 (GND), U5.6 (INH), U5.7 (VEE), U5.8 (VSS), U6.2 (GND), U10., U11.1 (GND), U29.6 (INH), U29.7 (VEE), U29.8 (VSS), V1.2
unnamed: D1.2, R12.2
unnamed: D5.2, R13.2
unnamed: D7.2, R22.1
unnamed: D9.2, R10.2
unnamed: D13.2, R15.2
unnamed: D14.1, R29.1
unnamed: D14.2, U14.2
unnamed: D15.1, R24.1
unnamed: D15.2, U13.2
unnamed: D16.1, R27.1
unnamed: D16.2, U15.2
unnamed: D17.1, R28.1
unnamed: D17.2, U16.2
unnamed: D18.1, R34.1
unnamed: D18.2, U17.2
unnamed: D19.1, R35.1
unnamed: D19.2, U18.2
unnamed: D20.1, R36.1
unnamed: D20.2, U19.2
unnamed: D21.1, R55.1
unnamed: D21.2, U20.2
unnamed: D22.1, R43.1
unnamed: D22.2, U21.2
unnamed: D23.1, R44.1
unnamed: D23.2, U22.2
unnamed: D24.1, R45.1
unnamed: D24.2, U23.2
unnamed: D25.1, R46.1
unnamed: D25.2, U24.2
unnamed: D26.1, R51.1
unnamed: D26.2, U25.2
unnamed: D27.1, R52.1
unnamed: D27.2, U26.2
unnamed: D28.1, R53.1
unnamed: D28.2, U27.2
unnamed: D29.1, R54.1
unnamed: D29.2, U28.2
unnamed: D30.2, R74.1
unnamed: D32.2, R78.1
unnamed: D33.2, R70.1
unnamed: J9.1, U28.1
unnamed: J9.4, U25.1
unnamed: J10.1, U24.1
unnamed: J10.2, U23.1
unnamed: J10.3, U22.1
unnamed: J10.4, U21.1
unnamed: J10.5, U20.1
unnamed: J10.6, U19.1
unnamed: J10.7, U18.1
unnamed: J10.8, U17.1
unnamed: J10.9, U16.1
unnamed: J10.10, U15.1
unnamed: J10.11, U13.1
unnamed: J10.12, U14.1
unnamed: C12.1, JP2.1 (A), L1.2, U4.3 (FB)
unnamed: K2.14, M1.2
unnamed: Q1.1 (B), R2.2
unnamed: Q3.1 (B), R1.2
unnamed: Q6.1 (B), R71.1
unnamed: Q6.3 (C), R72.1
unnamed: Q9.1 (G), R17.2, R21.2
unnamed: Q10.1 (B), R20.1
unnamed: Q10.3 (C), R21.1
unnamed: Q15.1 (G), R72.2, R73.2
unnamed: Q17.1 (B), R75.1
unnamed: Q17.3 (C), R76.1
unnamed: Q18.1 (G), R76.2, R77.2
unnamed: Q19.1 (B), R79.1
unnamed: Q19.3 (C), R80.1
unnamed: Q20.1 (G), R80.2, R81.2
unnamed: R23.2, R69.1
unnamed: R3.2, R4.2, U2.8 (VBUS)
unnamed: R5.2, U2.9 (~RST)
unnamed: R8.1, U2.11 (~SUSPEND)

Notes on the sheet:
Switches 24V
Indicator LED
ESP32 Power
ESP32 Board Connector
ESP32 Switches
24V PSU
GPIO0 is strapping pin for ESP32, must be be input only
Flyback
24V -> 5V Buck Converter
Temperature sensor
(4-20 mA)
To gates and optocoupler
ESP32 code & schematic source
Multiplexers
Current sensing
GPIO5 is strapping pin for ESP32, must be be input only
Mounting holes
Ultrasonic dust sensor
ESP32 USB-C
GPIO2 is strapping pin for ESP32, must be be input only
Not really how the connections look, but I didn't find a good three phase relay and motor symbol
ESP32
Main power relay
External Connections
Indicator light tower
BOOT
Optocoupler inputs
ESP32 USB-UART
Pressure sensor
Switches 5V
Switches GND
Auto Program: DTR RTS --> EN IO0 1 1 1 1 0 0 1 1 1 0 0 1 0 1 1 0
As per devkit c documentation.

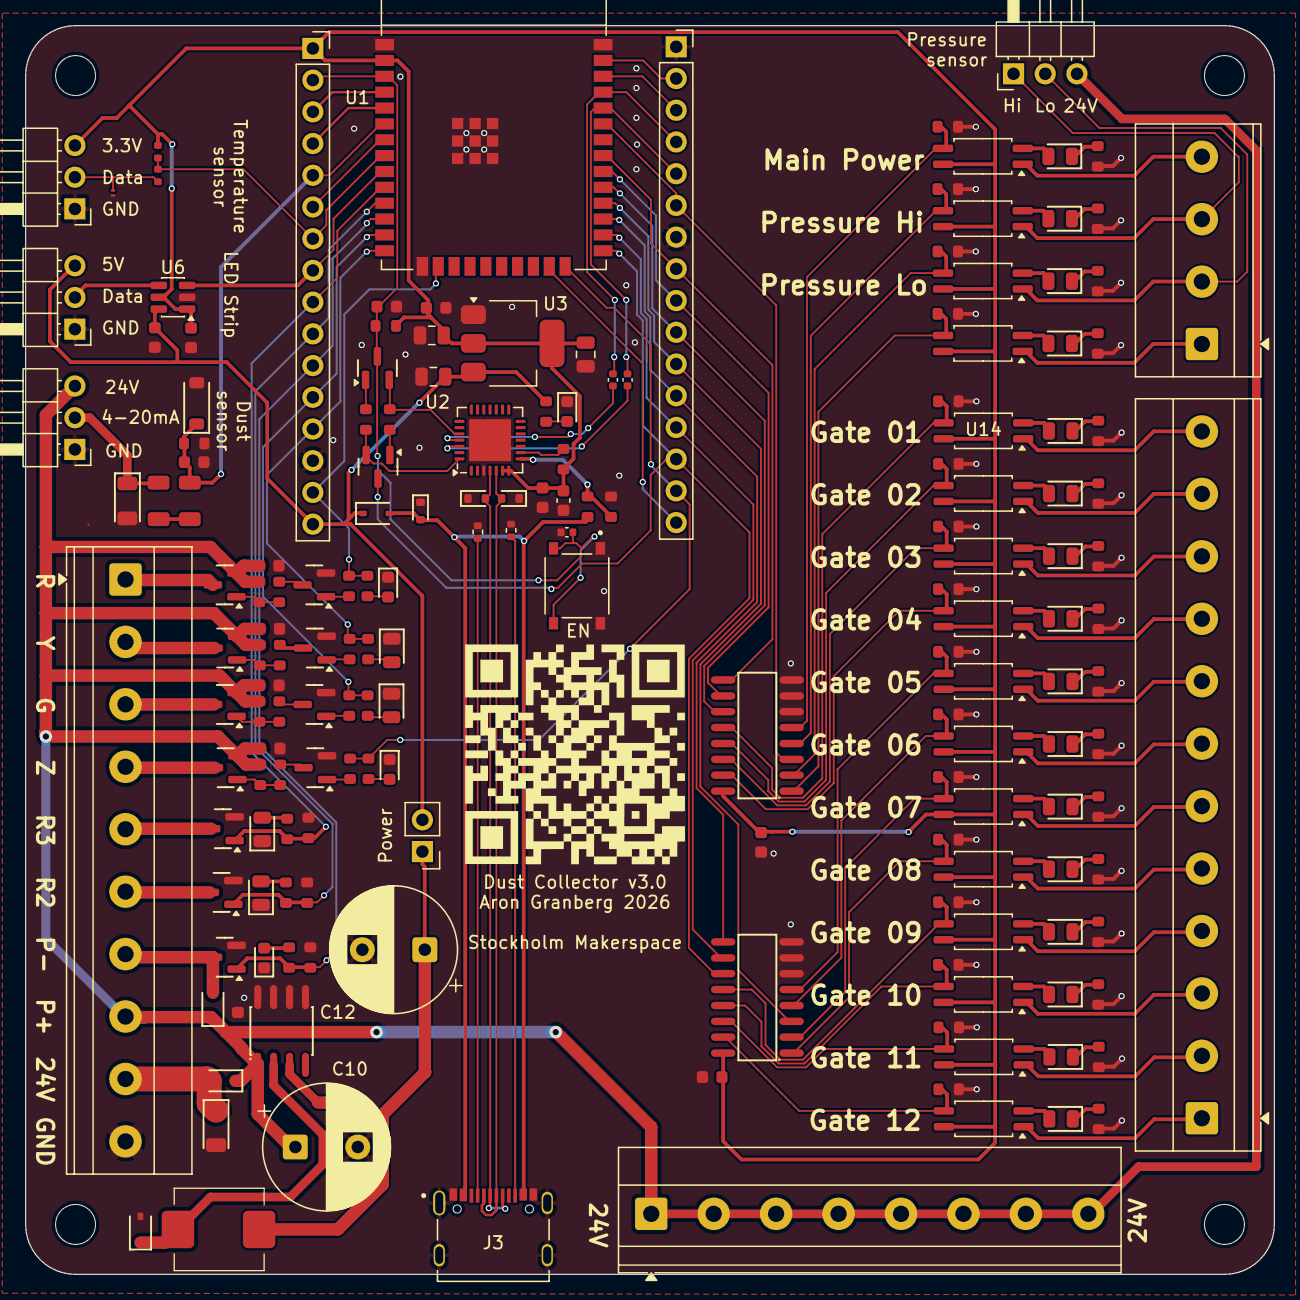
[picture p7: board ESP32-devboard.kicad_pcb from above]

Board: 2 copper layers, 100.0 x 100.0 mm, 179 parts (0 on the bottom side), 142 nets.

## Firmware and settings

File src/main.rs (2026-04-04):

#![deny(clippy::future_not_send)]
mod esp;
mod wifi;
mod wokwi;

use brevduva::{
    channel::{Channel, SerializationFormat},
    ReadWriteMode, SyncStorage,
};
use embedded_hal::delay::DelayNs;
use esp::init_esp;
use esp_idf_svc::{
    eventloop::EspSystemEventLoop,
    hal::{
        adc::{
            attenuation::DB_11,
            oneshot::{config::AdcChannelConfig, AdcChannelDriver},
        },
        gpio::{GpioError, IOPin, InputPin, Level, OutputPin, Pin, PinDriver, Pull},
        ledc::{config::TimerConfig, LedcDriver, LedcTimerDriver},
        peripheral::Peripheral,
        prelude::*,
        reset::ResetReason,
    },
    http::{client::EspHttpConnection, Method},
    nvs::EspDefaultNvsPartition,
    ota::EspOta,
    sys::{multi_heap_info_t, EspError},
};
use log::{error, info, warn};
use onewire::DS18B20;
use onewire::{DeviceSearch, OneWire};
use ordered_float::NotNan;
use serde::{Deserialize, Serialize};
use smart_leds::SmartLedsWrite;
use std::{
    fmt::Debug,
    sync::{Arc, Mutex},
    time::{Duration, Instant},
};
use wifi::start_wifi;
use wokwi::check_is_wokwi;

const MQTT_HOST: &str = "mqtt://arongranberg.com:1883";
const MQTT_CLIENT_ID: &str = "dust_collector";
const MQTT_USERNAME: &str = "wakeup_alarm";
const MQTT_PASSWORD: &str = "xafzz25nomehasff";

const PRESSURE_SENSOR_TRIGGERED_URL: &str =
    "https://api.makerspace.se/alerts/pressure_sensor_triggered";
const PRESSURE_SENSOR_RESET_URL: &str = "https://api.makerspace.se/alerts/pressure_sensor_reset";
const SEND_ALERT_MESSAGES: bool = false;

const DISTANCE_MIN: i32 = 250; // 250-
const DISTANCE_MAX: i32 = DISTANCE_CART_NOT_LOADED; // 1160-
                                                    // const DISTANCE_CART_NO_BAG_LOADED: i32 = 1170; // 1170+
const DISTANCE_CART_NOT_LOADED: i32 = 1180; // 1210+
const DISTANCE_NO_CART: i32 = 1290; // 1350+
const DISTANCE_NO_VALUE: i32 = 1600; // 1700+

#[derive(Debug, Clone, Copy, PartialEq, Hash, Serialize, Deserialize)]
enum DustLevel {
    Valid(NotNan<f32>),
    TooCloseToSensor,
    CartPresentNotLoaded,
    NoCart,
    SensorConfused,
}

fn map_dust_level(level: f32) -> DustLevel {
    if level > DISTANCE_NO_VALUE as f32 {
        DustLevel::SensorConfused
    } else if level > DISTANCE_NO_CART as f32 {
        DustLevel::NoCart
    } else if level > DISTANCE_CART_NOT_LOADED as f32 {
        DustLevel::CartPresentNotLoaded
    } else if level < DISTANCE_MIN as f32 {
        DustLevel::TooCloseToSensor
    } else {
        // Map to 0..1 range
        DustLevel::Valid(
            NotNan::new(1.0 - (level - DISTANCE_MIN as f32) / (DISTANCE_MAX - DISTANCE_MIN) as f32)
                .unwrap(),
        )
    }
}

fn main() {
    init_esp();

    warn!(
        "ESP max log level={:?} log crate max level={:?}",
        esp_idf_svc::log::EspLogger::default().get_max_level(),
        log::STATIC_MAX_LEVEL
    );
    esp_idf_svc::log::set_target_level("*", log::LevelFilter::Trace).unwrap();
    esp_idf_svc::log::set_target_level("brevduva", log::LevelFilter::Trace).unwrap();
    esp_idf_svc::log::set_target_level("fire-sensor", log::LevelFilter::Trace).unwrap();

    tokio::runtime::Builder::new_current_thread()
        .enable_all()
        .max_blocking_threads(2)
        .thread_stack_size(30000)
        .build()
        .unwrap()
        .block_on(async_main())
        .unwrap();
}

struct DebugLed {
    driver: LedcDriver<'static>,
}

impl DebugLed {
    fn new(driver: LedcDriver<'static>) -> Self {
        Self { driver }
    }

    pub fn resolution(&self) -> u32 {
        self.driver.get_max_duty()
    }

    fn set_duty_raw(&mut self, duty: u32) -> Result<(), EspError> {
        self.driver.set_duty(duty)
    }

    fn set_duty(&mut self, duty: f32) -> Result<(), EspError> {
        self.set_duty_raw((duty * self.resolution() as f32).round() as u32)
    }

    async fn blink(&mut self, times: usize, period: Duration) -> Result<(), EspError> {
        for _ in 0..times {
            self.set_duty(1.0)?;
            tokio::time::sleep(period).await;
            self.set_duty(0.0)?;
            tokio::time::sleep(period).await;
        }
        Ok(())
    }
}

fn successful_boot() {
    let mut ota = EspOta::new().expect("obtain OTA instance");
    // This will fail when flashing the app the normal way (not OTA), so we ignore the result.
    ota.mark_running_slot_valid().ok();
}

enum OneWireError {
    DeviceNotFound,
    Onewire(onewire::Error<GpioError>),
}

impl Debug for OneWireError {
    fn fmt(&self, f: &mut std::fmt::Formatter<'_>) -> std::fmt::Result {
        match self {
            OneWireError::DeviceNotFound => write!(f, "OneWire device not found"),
            OneWireError::Onewire(e) => write!(f, "OneWire error: {:?}", e),
        }
    }
}

impl From<onewire::Error<GpioError>> for OneWireError {
    fn from(error: onewire::Error<GpioError>) -> Self {
        OneWireError::Onewire(error)
    }
}

fn find_onewire_device<
    T: embedded_hal::digital::OutputPin<Error = GpioError>
        + embedded_hal::digital::InputPin<Error = GpioError>,
>(
    wire: &mut OneWire<T>,
    family_code: u8,
    delay: &mut impl DelayNs,
) -> Result<onewire::Device, OneWireError> {
    let mut search = DeviceSearch::new();
    while let Some(device) = wire.search_next(&mut search, delay)? {
        if device.address[0] == family_code {
            return Ok(device);
        } else {
            // Not the right family code, continue searching
        }
    }
    Err(OneWireError::DeviceNotFound)
}

/// Driver for a DS18B20 temperature sensor on a OneWire bus
struct TemperatureSensor<
    T: embedded_hal::digital::OutputPin<Error = GpioError>
        + embedded_hal::digital::InputPin<Error = GpioError>,
> {
    sensor: DS18B20,
    wire: OneWire<T>,
    delay: esp_idf_svc::hal::delay::Ets,
}

impl<
        T: embedded_hal::digital::OutputPin<Error = GpioError>
            + embedded_hal::digital::InputPin<Error = GpioError>,
    > TemperatureSensor<T>
{
    fn new(one: T) -> Result<Self, OneWireError> {
        let mut wire = OneWire::new(one, false);

        let mut delay = esp_idf_svc::hal::delay::Ets;
        wire.reset(&mut delay)?;

        // Search for devices
        let device = find_onewire_device(&mut wire, onewire::ds18b20::FAMILY_CODE, &mut delay)?;

        let ds18b20 = onewire::DS18B20::new(device).unwrap();
        return Ok(TemperatureSensor {
            sensor: ds18b20,
            wire,
            delay,
        });
    }

    fn measure(&mut self) -> Option<u16> {
        // request sensor to measure temperature
        let resolution = self
            .sensor
            .measure_temperature(&mut self.wire, &mut self.delay)
            .unwrap();

        // wait for compeltion, depends on resolution
        self.delay.delay_ms(resolution.time_ms() as u32);

        // read temperature
        let temperature = self
            .sensor
            .read_temperature(&mut self.wire, &mut self.delay)
            .unwrap();
        Some(temperature)
    }
}

/// Driver for an 8-channel digital multiplexer
/// Like the CD4051BM96
struct Multiplexer8<T: embedded_hal::digital::OutputPin, I: embedded_hal::digital::InputPin> {
    selector_pins: [T; 3],
    data_pin: I,
    delay: esp_idf_svc::hal::delay::Ets,
}

impl<
        T: embedded_hal::digital::OutputPin<Error = E>,
        I: embedded_hal::digital::InputPin<Error = E>,
        E,
    > Multiplexer8<T, I>
{
    fn new(selector_pins: [T; 3], data_pin: I, delay: esp_idf_svc::hal::delay::Ets) -> Self {
        Self {
            selector_pins,
            data_pin,
            delay,
        }
    }

    fn select_channel(&mut self, channel: u8) -> Result<(), E> {
        for (i, pin) in self.selector_pins.iter_mut().enumerate() {
            if (channel & (1 << i)) != 0 {
                pin.set_high()?;
            } else {
                pin.set_low()?;
            }
        }
        Ok(())
    }

    fn read_data(&mut self) -> Result<bool, E> {
        self.data_pin.is_high()
    }

    fn channel_is_high(&mut self, channel: u8) -> Result<bool, E> {
        self.select_channel(channel)?;
        // The multiplexer should settle in 6ns or so, which is smaller than even the ESP32's instruction latency.
        // However, the wires are long and it takes some time for the signal to stabilize.
        // The ESP32 also has some capacitance on its input pins
        // which, according to my calculations takes around 200us to charge/discharge through
        // the built-in pull-up/pull-down resistors.
        self.delay.delay_us(200);

        // Even though we delay some time, we still get occasional unstable readings.
        // So we read the value multiple times and use majority voting.
        // This seems to eliminate all noise.
        let mut high_count = 0;
        for _ in 0..4 {
            if self.read_data().map_err(|e| e.into())? {
                high_count += 1;
            }
            self.delay.delay_us(20);
        }
        if high_count > 2 {
            Ok(true)
        } else {
            Ok(false)
        }

        // self.read_data().map_err(|e| e.into())
    }
}

/// Driver for a 16-channel digital multiplexer composed of two 8-channel multiplexers
struct Multiplexer16<
    T: embedded_hal::digital::OutputPin,
    I1: embedded_hal::digital::InputPin,
    I2: embedded_hal::digital::InputPin,
> {
    mux1: Multiplexer8<T, I1>,
    mux2: Multiplexer8<T, I2>,
}

impl<
        T: embedded_hal::digital::OutputPin<Error = E>,
        I1: embedded_hal::digital::InputPin<Error = E>,
        I2: embedded_hal::digital::InputPin<Error = E>,
        E,
    > Multiplexer16<T, I1, I2>
{
    fn new(mux1: Multiplexer8<T, I1>, mux2: Multiplexer8<T, I2>) -> Self {
        Self { mux1, mux2 }
    }

    fn channel_is_high(&mut self, channel: u8) -> Result<bool, E> {
        if channel < 8 {
            self.mux1.channel_is_high(channel)
        } else {
            self.mux2.channel_is_high(channel - 8)
        }
    }
}
enum PostError {
    EspError(EspError),
    Status(u16),
}

impl From<EspError> for PostError {
    fn from(error: EspError) -> Self {
        PostError::EspError(error)
    }
}

impl Debug for PostError {
    fn fmt(&self, f: &mut std::fmt::Formatter<'_>) -> std::fmt::Result {
        match self {
            PostError::EspError(e) => write!(f, "EspError: {}", e),
            PostError::Status(s) => write!(f, "HTTP Status Error: {}", s),
        }
    }
}

async fn post_url(url: &'static str) -> Result<(), PostError> {
    tokio::task::spawn_blocking(move || {
        // Send POST request using esp-idf API
        let mut client = EspHttpConnection::new(&esp_idf_svc::http::client::Configuration {
            crt_bundle_attach: Some(esp_idf_svc::sys::esp_crt_bundle_attach),
            buffer_size: Some(32 * 1024),
            timeout: Some(Duration::from_secs(10)),
            ..Default::default()
        })
        .map_err(PostError::EspError)?;

        let headers = [("Content-Type", "application/json")];
        let body = b"{}"; // Empty JSON body

        client.initiate_request(Method::Post, url, &headers)?;
        client.write_all(body).map_err(PostError::EspError)?;
        client.initiate_response().map_err(PostError::EspError)?;

        if client.status() == 200 {
            info!("Post message sent successfully to {url}");
        } else {
            error!(
                "Failed to send post message to {url}. Status: {}",
                client.status()
            );
            return Err(PostError::Status(client.status()));
        }

        Ok::<(), PostError>(())
    })
    .await
    .unwrap()
}

async fn maybe_enter_safe_mode(debug_led: &mut DebugLed, status_channel: &Channel<String>) {
    match ResetReason::get() {
        ResetReason::Panic | ResetReason::TaskWatchdog | ResetReason::CPULockup => {
            error!(
                "Previous reset was due to panic or watchdog. Entering safe mode for 30 seconds."
            );
            status_channel
                .send(
                    "Restart was due to panic or watchdog. Entering safe mode for 30 seconds."
                        .to_string(),
                )
                .await;
            // Sleep
            debug_led
                .blink(30, Duration::from_millis(500))
                .await
                .unwrap();
            status_channel.send("Exiting safe mode.".to_string()).await;
            info!("Exiting safe mode.");
        }
        r => {
            info!("Reset reason: {:?}", r);
        }
    }
}
const LED_STRIP_NUM_LEDS: usize = 44;

type SpiBus<'d> = esp_idf_svc::hal::spi::SpiBusDriver<'d, esp_idf_svc::hal::spi::SpiDriver<'d>>;
const DUST_LEVEL_WARNING_THRESHOLD: f32 = 0.65;
const DUST_LEVEL_CRITICAL_THRESHOLD: f32 = 0.8;

fn create_spi_bus<'d>(
    spi: impl esp_idf_svc::hal::peripheral::Peripheral<P = impl esp_idf_svc::hal::spi::SpiAnyPins> + 'd,
    sclk: impl esp_idf_svc::hal::peripheral::Peripheral<P = impl OutputPin> + 'd,
    mosi: impl esp_idf_svc::hal::peripheral::Peripheral<P = impl OutputPin> + 'd,
) -> Result<SpiBus<'d>, Box<dyn std::error::Error>> {
    use esp_idf_svc::hal::spi::{config::Config, Dma, SpiBusDriver, SpiDriver, SpiDriverConfig};

    let spi_driver = SpiDriver::new(
        spi,
        sclk,
        mosi,
        None::<esp_idf_svc::hal::gpio::AnyIOPin>,
        &SpiDriverConfig::new().dma(Dma::Auto(LED_STRIP_NUM_LEDS * 12 + 140)),
    )?;

    let config = Config::new().baudrate(3.MHz().into()).write_only(true);
    Ok(SpiBusDriver::new(spi_driver, &config)?)
}

fn run_led_test_pattern<W: SmartLedsWrite>(ws2812: &mut W) -> Result<(), W::Error>
where
    W::Color: From<smart_leds::RGB8>,
{
    let colors: [(u8, u8, u8); 4] = [
        (255, 0, 0), // Red
        (0, 255, 0), // Green
        (0, 0, 255), // Blue
        (0, 0, 0),   // Off
    ];

    for &(r, g, b) in &colors {
        let pixels = std::iter::repeat(smart_leds::RGB8::new(r, g, b)).take(LED_STRIP_NUM_LEDS);
        ws2812.write(pixels)?;
        std::thread::sleep(Duration::from_millis(500));
    }

    Ok(())
}

const MOVING_ARROWS_SPEED: f32 = 10.0;
const MOVING_ARROWS_LENGTH: f32 = 16.0;
const INTRO_FADE: f32 = 5.0;

fn ease_out_cubic(x: f32) -> f32 {
    1.0 - (1.0 - x).powi(3)
}

fn update_led_strip<W: SmartLedsWrite>(
    ws2812: &mut W,
    pixels: &mut [smart_leds::RGB8; LED_STRIP_NUM_LEDS],
    dust_level: DustLevel,
    animation_time: f32,
) where
    W::Color: From<smart_leds::RGB8>,
    W::Error: Debug,
{
    let intro_fade = (animation_time.min(INTRO_FADE) / INTRO_FADE).clamp(0.0, 1.0);
    let intro_fade_staggered =
        ((animation_time - INTRO_FADE / 2.0).min(INTRO_FADE) / INTRO_FADE).clamp(0.0, 1.0);
    let global_brightness = intro_fade;

    match dust_level {
        DustLevel::TooCloseToSensor | DustLevel::SensorConfused => {
            // Orange white noise
            let tick = (animation_time * 1.0) as u32;
            for (i, pixel) in pixels.iter_mut().enumerate() {
                // Simple deterministic noise from tick + position
                let hash = (i as u32 + tick) % 2;
                let mut brightness = hash as f32;
                brightness *= global_brightness;

                let r = (255.0 * brightness) as u8;
                let g = (100.0 * brightness) as u8;
                *pixel = smart_leds::RGB8::new(r, g, 0);
            }

            // (0..LED_STRIP_NUM_LEDS)
            //     .map(|i| {
            //         // Simple deterministic noise from tick + position
            //         let hash = (tick
            //             .wrapping_mul(1237)
            //             .wrapping_add((i * 7) as u32)
            //             .wrapping_mul(512353))
            //             % 256;
            //         let mut brightness = (hash as f32 / 255.0).powi(2);
            //         brightness *= global_brightness;

            //         let r = (255.0 * brightness) as u8;
            //         let g = (100.0 * brightness) as u8;
            //         smart_leds::RGB8::new(r, g, 0)
            //     })
        }
        DustLevel::CartPresentNotLoaded | DustLevel::NoCart => {
            for (i, pixel) in pixels.iter_mut().enumerate() {
                let mut x = (((i as f32) - (animation_time * MOVING_ARROWS_SPEED))
                    % MOVING_ARROWS_LENGTH)
                    / MOVING_ARROWS_LENGTH;
                if x < 0.0 {
                    x += 1.0;
                }

                let brightness = x.powi(2) * global_brightness;
                let r = (255.0 * brightness) as u8;
                let g = (100.0 * brightness) as u8;
                *pixel = smart_leds::RGB8::new(r, g, 0);
            }
        }
        DustLevel::Valid(value) => {
            let value = value.into_inner() * ease_out_cubic(intro_fade_staggered);
            let lit_count = value * LED_STRIP_NUM_LEDS as f32;
            let warning_led =
                (DUST_LEVEL_WARNING_THRESHOLD * LED_STRIP_NUM_LEDS as f32).round() as usize;
            let critical_led =
                (DUST_LEVEL_CRITICAL_THRESHOLD * LED_STRIP_NUM_LEDS as f32).round() as usize;
            let intro_threshold_led = LED_STRIP_NUM_LEDS as f32 * ease_out_cubic(intro_fade);

            for (i, pixel) in pixels.iter_mut().enumerate() {
                let mut brightness: f32 = (lit_count - i as f32).clamp(0.14, 1.0);
                let intro_brightness = (intro_threshold_led - i as f32).clamp(0.0, 1.0);
                brightness = (brightness * intro_brightness).powi(2);

                let col = if i >= critical_led {
                    smart_leds::RGB8::new(255, 0, 0)
                } else if i >= warning_led {
                    smart_leds::RGB8::new(255, 100, 0)
                } else {
                    smart_leds::RGB8::new(0, 255, 0)
                };
                *pixel = smart_leds::RGB {
                    r: (col.r as f32 * brightness) as u8,
                    g: (col.g as f32 * brightness) as u8,
                    b: (col.b as f32 * brightness) as u8,
                };
            }
        }
    };

    if let Err(e) = ws2812.write(pixels.iter().copied().rev()) {
        error!("Failed to update LED strip: {:?}", e);
    }
}

async fn run_led_animation(spi_bus: SpiBus<'static>, dust_level: Arc<Mutex<DustLevel>>) {
    let mut buf = vec![0u8; LED_STRIP_NUM_LEDS * 12 + 140];
    let mut ws2812 = ws2812_spi::prerendered::Ws2812::new(spi_bus, &mut buf);
    let mut pixels = [smart_leds::RGB8::default(); LED_STRIP_NUM_LEDS];

    let start = Instant::now();
    loop {
        let animation_time = Instant::now().duration_since(start).as_secs_f32();

        let level = *dust_level.lock().unwrap();
        update_led_strip(&mut ws2812, &mut pixels, level, animation_time);
        // update_led_strip(
        //     &mut ws2812,
        //     DustLevel::Valid(NotNan::new(0.75).unwrap()),
        //     animation_time,
        // );
        tokio::time::sleep(Duration::from_millis(30)).await;
    }
}
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

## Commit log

2025-11-09 Initial commit.
    [partitions.csv, schematic.kicad_pcb, schematic.kicad_sch]
2025-11-13 Update schematic.
    [schematic.kicad_sch]
2025-11-18 Make more resilient against missing sensors.
    [main.rs]
2025-11-19 Clean up code a bit, and change pins around to match the schematic.
2025-11-26 When machine turns off due to safety relays, ignore open gates individually instead of having to close all gates to get it working again.
2026-02-19 WIP on new schematic
    [CSP-USC16-TR--3DModel-STEP-468060.STEP, ESP32-WROOM-32E.STEP, ESP32-devboard.kicad_pcb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]
2026-02-21 Schematic updates
    [ESP32-devboard.kicad_pcb, ESP32-devboard.kicad_sch]
2026-02-24 Schematic updates - Ordered from JLCPCB
    [ESP32-devboard.kicad_pcb, ESP32-devboard.kicad_sch]
2026-03-07 Organize schematic
    [ESP32-devboard.kicad_sch]
2026-03-07 Update code to fit new pcb
2026-03-15 Add ESD protection and other safety improvements
    [ESP32-devboard.kicad_pcb, ESP32-devboard.kicad_sch]
2026-03-21 Final tweaks. Ordered from JLCPCB
    [ESP32-devboard.kicad_pcb, ESP32-devboard.kicad_sch]
2026-04-03 WIP on leds
2026-04-03 Improve led strip
2026-04-03 Tweak led animation
